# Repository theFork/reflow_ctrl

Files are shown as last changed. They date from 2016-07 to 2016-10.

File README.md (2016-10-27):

# Reflow Controller
A simple-as-possible reflow oven controller. It uses the [uMIDI](https://github.com/theFork/uMIDI) board and library as microcontroller and for USB host communication.

* 3.3V and 5V sourced from the controller board (uMIDI)
* Solid state relais Finder 77.11..9.8251 (15A) to power an oven from a low current 5V signal
* AD converter (MAX6675), connected to type-K thermocoupler
* Graphical host software written in Java

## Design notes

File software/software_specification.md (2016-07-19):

# System Overview
The system consists of a
* host system (linux-capable computer), a
* uMIDI board, the
* reflow controller board, a
* type K thermocouple as well as a
* a pizza oven.

------------------------------------------------------------------------------

# MCU firmware

## Reflow Board Interface
The reflow board IS connected to uMIDI header GPIO1 as follows:

| Pin | Function |
|-----|---|
| 2 | PWR |
| 5 | SCK |
| 7 | ~CS |
| 9 | MISO |

The reflow board IS equipped with a MAX6675 cold junction compensator and
AD-conversion chip.

## Host Interface
The uMIDI board is attached to the host system via USB and acts as a TTY device.

### Oven Shot
Activates the oven for a given duration in milliseconds:
``` 
shot <T>
```

The uMIDI board activates the oven for the given duration.
After activation it acknoledges by echoeing the shot command
with the given duration.

### Measure Temperature
Using the temp command

```
temp
```

the host requests the current temperature. The uMIDI replies in celius.

------------------------------------------------------------------------------

# Host Software
* Implemented in Python (3 or greater)
* Command line interface
* Create a temperature plot
* Implement temperature control to apply a given temperature profile

## Temperature profile
A profile consists of the following parameters, wheras upper case T stands for
a temperature whereas a lower case t represents a duration.
* T_preheat
* t_preheat
* T_reflow
* t_reflow
* T_max

The controller should not exceed T_max for more than 5s.

The profile MAY also define a maximum ramp down rate.

## Temperature plot
* A time curve of the temperature
* MUST be updated automaticaly
* SHOULD include a live view of the current temperature

SHOULKD be implemented using a python plot library (pyplot or mathplotlib), MAY also be
implemented using Gnuplot.

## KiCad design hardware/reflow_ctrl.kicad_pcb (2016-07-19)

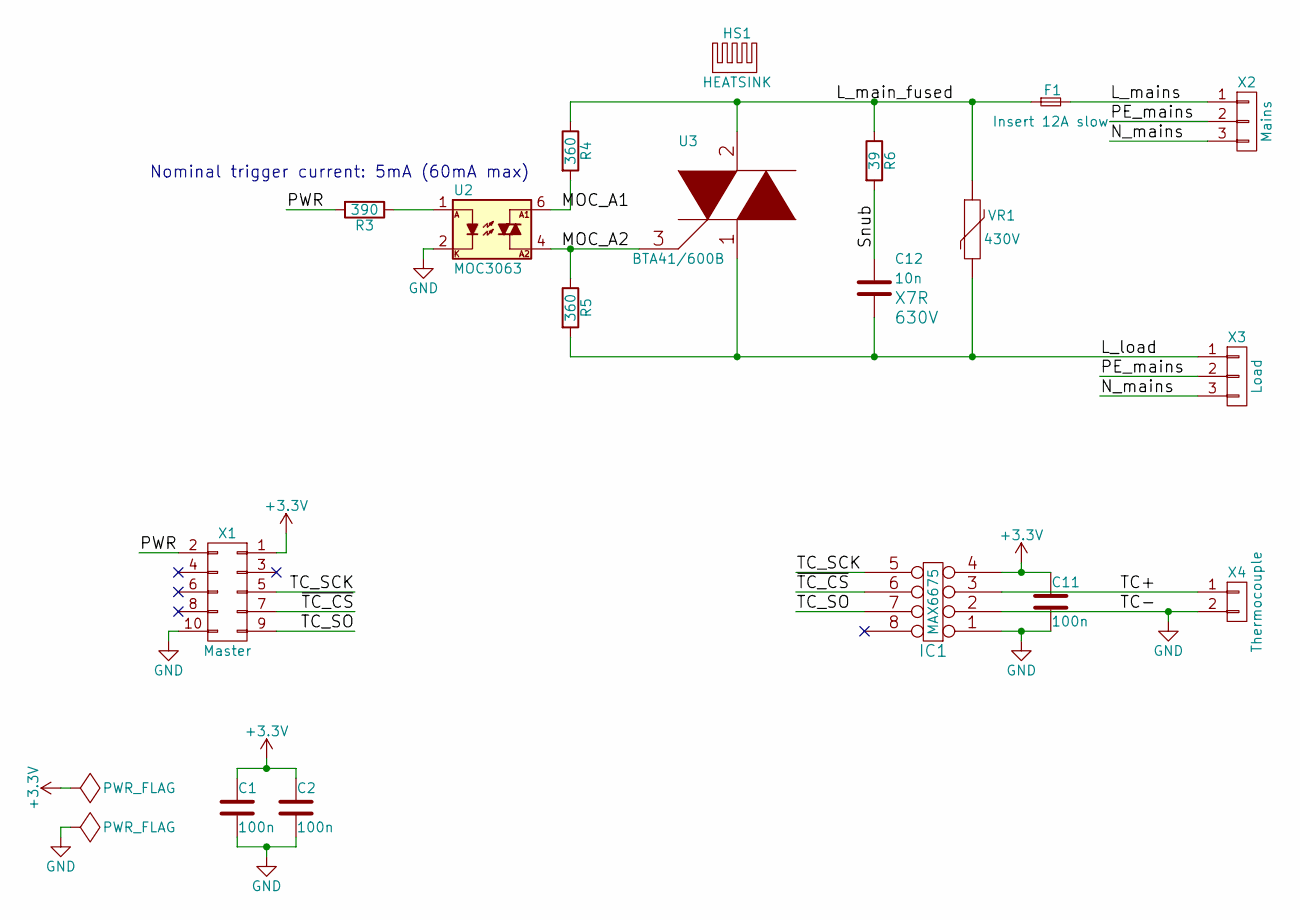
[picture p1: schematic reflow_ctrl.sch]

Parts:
C1, C2, C11: 100n; Pas_0603
C12: 10n; Pas_1206; Voltage 630V
F1: Insert 12A slow; Fuseholder_Schurter_20x5; Manufacturer Part Number 0031.8231
HS1: HEATSINK; Mech-Heatsink_Fischer_SK129_STS; Manufacturer Part Number SK 129-50 STS
IC1: MAX6675; SOIC-8_3.9x4.9mm_Pitch1.27mm
R3: 390; Pas_0603
R4, R5: 360; Pas_1206
R6: 39; Pas_1206
U2: MOC3063; Semi-Optotriac_MOC3063-SMD; Manufacturer Part Number MOC3063SR2VM
U3: BTA41/600B; TO-247_Vertical_Neutral123_largePads; Manufacturer Part Number BTA41-600BRG
VR1: 430V; RV_Disc_D7_W4.5_P5; Manufacturer Part Number S14K275
X1: Master; Con-boxed_header-THT
X2: Mains; Mains_Solder
X3: Load; Mains_Solder
X4: Thermocouple; Pinhead1-2

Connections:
+3V3: C1.1, C2.1, C11.1, IC1.4, X1.1
/L_load: C12.2, R5.2, U3.1, VR1.2, X3.1
/L_main_fused: F1.1, R4.1, R6.1, U3.2, VR1.1
/L_mains: F1.2, X2.1
/MOC_A1: R4.2, U2.6
/MOC_A2: R5.1, U2.4, U3.3
/N_mains: X2.3, X3.3
/PE_mains: X2.2, X3.2
/PWR: R3.2, X1.2
/Snub: C12.1, R6.2
/TC+: IC1.3, X4.1
/TC_SCK: IC1.5, X1.5
/TC_SO: IC1.7, X1.9
/~TC_CS: IC1.6, X1.7
GND: C1.2, C2.2, C11.2, IC1.1, IC1.2, U2.2, X1.10, X4.2
unnamed: R3.1, U2.1

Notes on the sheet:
Nominal trigger current: 5mA (60mA max)

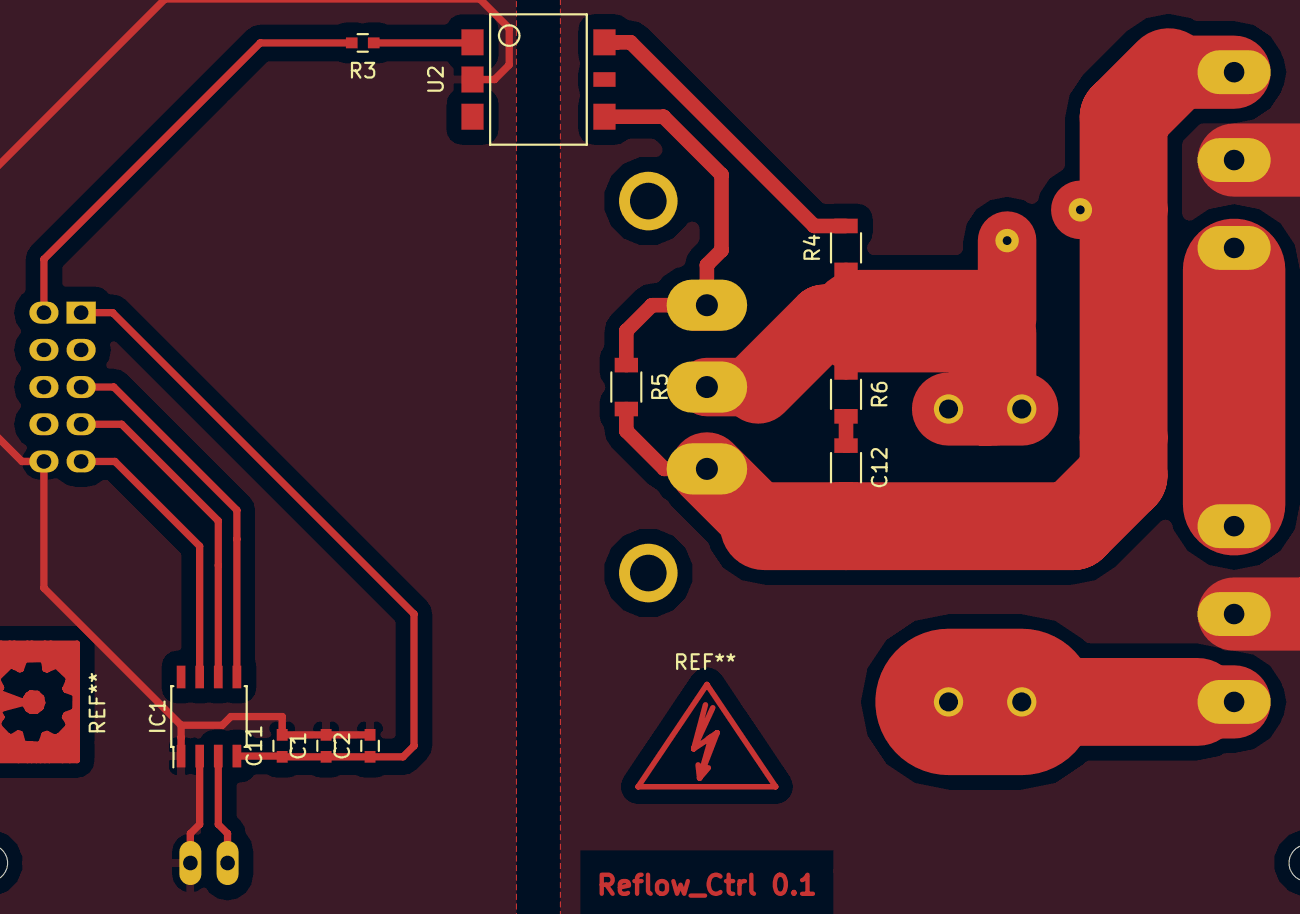
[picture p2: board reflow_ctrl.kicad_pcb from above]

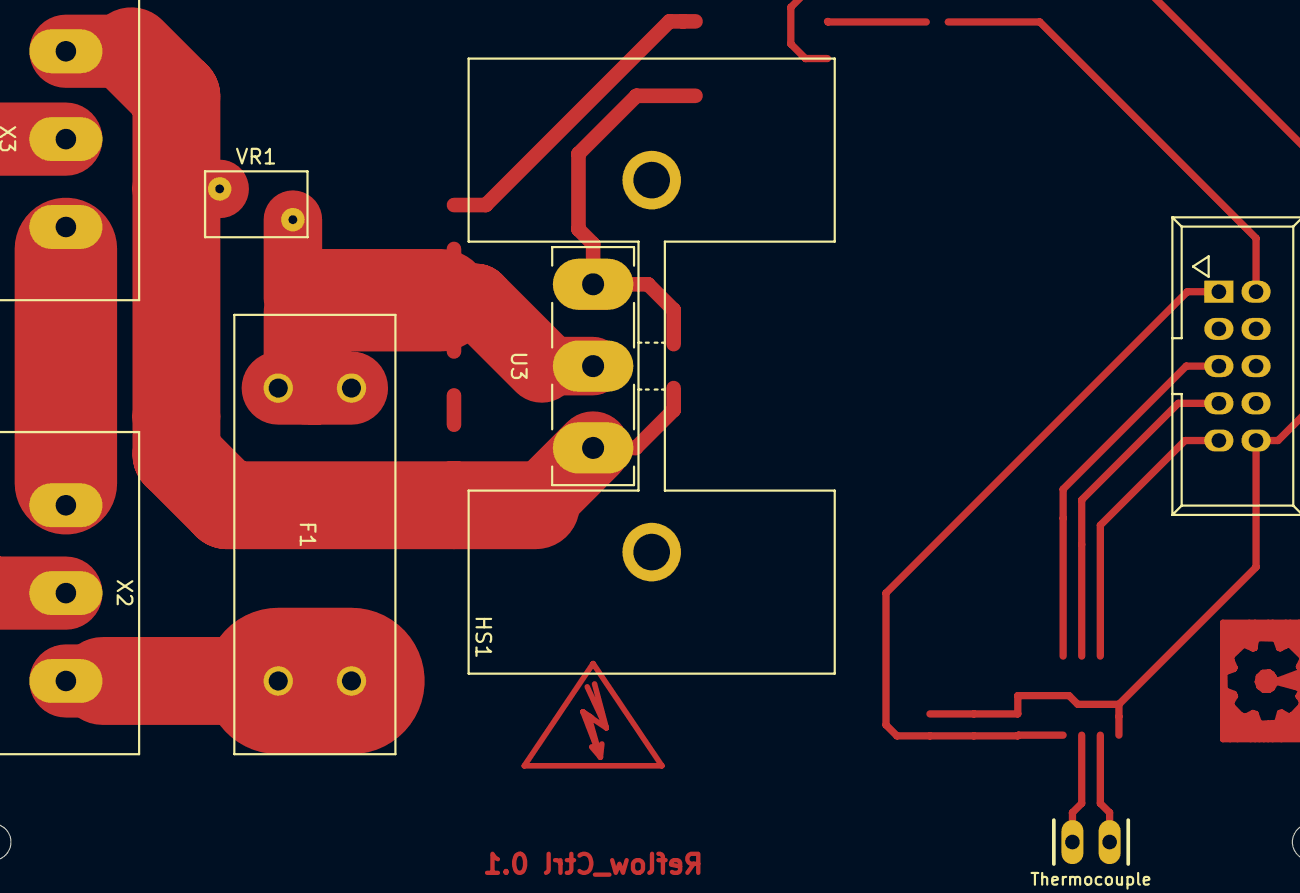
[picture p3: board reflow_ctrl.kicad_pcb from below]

Board: 2 copper layers, 18 parts (8 on the bottom side), 16 nets.

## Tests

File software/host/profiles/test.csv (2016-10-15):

# Temperature profile for testing
# Syntax: <Duration> | <Temperature>
# <Duration> | <TemperatureStart>..<TemperatureEnd>
180 | 50..100
180 | 80
180 | 80..150
180 | 130

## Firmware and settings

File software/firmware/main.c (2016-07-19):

/// \file
/// \brief      Entry point and main loop of the uMIDI firmware

/*
 * Copyright 2012-2015 Sebastian Neuser
 *
 * This file is part of the uMIDI firmware.
 *
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
 * You should have received a copy of the GNU General Public License
 * along with the uMIDI firmware.  If not, see <http://www.gnu.org/licenses/>.
 */

#include <avr/interrupt.h>
#include <avr/wdt.h>

#include "lib/background_tasks.h"
#include "lib/gpio.h"
#include "lib/leds.h"
#include "lib/serial_communication.h"
#include "lib/spi.h"
#include "lib/system.h"
#include "lib/usb.h"

#include "config.h"
#include "app.h"


////////////////////////////////////////////////////////////////
//                     V A R I A B L E S                      //
////////////////////////////////////////////////////////////////



////////////////////////////////////////////////////////////////
//      F U N C T I O N S   A N D   P R O C E D U R E S       //
////////////////////////////////////////////////////////////////

/// \brief      Initialization and endless loop with background tasks
int main( void )
{
    // Configure clock and timers
    configure_system_clock();
    enable_usb_pll();

    // Initialize modules
    init_leds_module();
    init_gpio_module(gpio_mappings, gpio_mappings_size);
    init_spi_module(&spi_config);
    init_background_tasks(high_frequency_tasks, high_frequency_tasks_size,
                          mid_frequency_tasks,  mid_frequency_tasks_size,
                          low_frequency_tasks,  low_frequency_tasks_size);
    init_usb_module();
    init_serial_communication(serial_commands, serial_commands_size);

    restore_temp_offset();

    // set watchdog for 128ms
    wdt_enable(WDT_PER_128CLK_gc);

    // enable interrupts
    PMIC.CTRL = PMIC_LOLVLEN_bm;
    sei();

    // Blink green LED
    blink_led(LED_GREEN, F_TASK_SLOW);

    // Main loop
    while (true) {
        process_background_tasks();
        wdt_reset();
    }

    return 0;
}

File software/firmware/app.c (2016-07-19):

/// \file
/// \brief      Implementation of an application specific module
/// \see        app.h

/*
 * Copyright 2015 Sebastian Neuser
 *
 * This file is part of the uMIDI firmware.
 *
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
 * You should have received a copy of the GNU General Public License
 * along with the uMIDI firmware.  If not, see <http://www.gnu.org/licenses/>.
 */

#include <stdlib.h>
#include <string.h>

#include "lib/leds.h"
#include "lib/usb.h"

#include "config.h"
#include "app.h"


////////////////////////////////////////////////////////////////
//                     V A R I A B L E S                      //
////////////////////////////////////////////////////////////////

static uint16_t heater_timeout = 0;

static int16_t temp_offset = 0;
static uint16_t temp_offset_eemem EEMEM;


////////////////////////////////////////////////////////////////
//      F U N C T I O N S   A N D   P R O C E D U R E S       //
////////////////////////////////////////////////////////////////

/// \brief      Handler for the `led` command
bool exec_led(const char* command)
{
    // Abort if the command is malformed
    if (strlen(command) != 7 || command[3] != ' ' || command[5] != ' ') {
        usb_puts("Malformed command" USB_NEWLINE);
        return false;
    }

    // Parse LED(s) to manipulate
    struct led* led;
    switch (command[4]) {
    case 'g':
        led = led_green;
        break;

    case 'r':
        led = led_red;
        break;

    default:
        usb_puts("No such LED" USB_NEWLINE);
        return false;
    }

    // Parse and execute action
    switch (command[6]) {
    case 'b':
        blink_led(led, F_TASK_SLOW);
        break;

    case 'f':
        flash_led(led);
        break;

    case 't':
        toggle_led(led);
        break;

    default:
        usb_puts("No such action" USB_NEWLINE);
        return false;
    }

    return true;
}

bool exec_shot(const char * const command)
{
    if (strlen(command) < 6 || command[4] != ' ') {
        usb_puts("Malformed command" USB_NEWLINE);
        return false;
    }

    uint16_t length = strtol(command+5, NULL, 10);
    usb_printf("Enabling heater for %u ms" USB_NEWLINE, length*10);

    // update (i.e. overwrite) countdown
    heater_timeout = length;

    return true;
}

bool exec_offs(const char* command)
{
    if (strlen(command) < 6 || command[4] != ' ') {
        usb_puts("Malformed command" USB_NEWLINE);
        return false;
    }

    temp_offset = strtol(command+5, NULL, 10);
    eeprom_write_word(&temp_offset_eemem, temp_offset);
    return true;
}

bool exec_temp(const char * const command)
{
    if (strlen(command) != 4) {
        usb_puts("Malformed command" USB_NEWLINE);
        return false;
    }

    // "Send" dummy value to recieve data
    spi_select(true);
    uint16_t input_word = spi_transceive(0);
    spi_select(false);

    // Abort if no thermo couple is connected
    if (input_word & 0x4) {
        usb_puts("Error: No thermo couple connected!" USB_NEWLINE ":-(");
        return true;
    }

    // Parse and print temperature
    uint16_t temperature = input_word >> 3;
    temperature += temp_offset;

    const char* fractional = "00";
    switch (temperature % 4) {
        case 3:
            fractional = "75";
            break;
        case 2:
            fractional = "50";
            break;
        case 1:
            fractional = "25";
            break;
        default:
            break;
    }
    temperature >>= 2;

    usb_printf("Temperature: %4u.%s" USB_NEWLINE, temperature, fractional);
    return true;
}

void heat_control_task(void)
{
    // Heater is on in case there is still timeout left
    if (heater_timeout > 0) {
        heater_timeout--;
        gpio_drive_high(gpio.header1.pin2);
        set_led(led_red, true);
    }
    // Turn off the heater afterwards
    else {
        gpio_drive_low(gpio.header1.pin2);
        set_led(led_red, false);
    }
}

void restore_temp_offset(void)
{
    temp_offset = eeprom_read_word(&temp_offset_eemem);
}

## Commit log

2016-01-31 Initial schematic
    [reflow_ctrl.kicad_pcb, reflow_ctrl.sch]
2016-01-31 Add uMIDI.pretty footprints module
2016-01-31 Assign some footprints
    [reflow_ctrl.sch]
2016-01-31 Move protection earth between L and N
    [reflow_ctrl.sch]
2016-01-31 Add and assign mains terminal footprint
    [reflow_ctrl.sch]
2016-01-31 Add supplier links and optotriac footprint
    [reflow_ctrl.sch]
2016-02-01 Sanetize output circuit; Add varistor
    [reflow_ctrl.sch]
2016-02-01 Add fuse holder footprint
    [reflow_ctrl.sch]
2016-02-01 Assign all footprints
    [reflow_ctrl.sch]
2016-02-01 Initial placement; Select pcb outline; Add TODO
    [reflow_ctrl.kicad_pcb, reflow_ctrl.sch]
2016-02-03 Use big USB-B THT connector
    [reflow_ctrl.kicad_pcb, reflow_ctrl.sch]
2016-02-15 Remove MCU circuit (use external uMIDI)
    [reflow_ctrl.sch]
2016-02-15 ERC clean
    [reflow_ctrl.sch]
2016-02-15 Update uMIDI.pretty: Fix footprint syntax (?)
2016-02-15 Update board
    [reflow_ctrl.kicad_pcb, reflow_ctrl.sch]
2016-02-15 Prepare net classes
    [reflow_ctrl.kicad_pcb, reflow_ctrl.sch]
2016-02-19 Shrink schematic page size
    [reflow_ctrl.sch]
2016-02-19 Add mounting holes
    [reflow_ctrl.kicad_pcb]
2016-02-19 Disentangle connector pinout; Start placement
    [reflow_ctrl.kicad_pcb, reflow_ctrl.sch]
2016-02-19 Add and use uMIDI.pretty generic smd packages
    [reflow_ctrl.kicad_pcb, reflow_ctrl.sch]
2016-02-19 Place and lock heatsink and triac
    [reflow_ctrl.kicad_pcb, reflow_ctrl.sch]
2016-02-19 Start place and route
    [reflow_ctrl.kicad_pcb]
2016-02-20 Revise placement; Route
    [reflow_ctrl.kicad_pcb]
2016-02-20 Finish routing
    [reflow_ctrl.kicad_pcb]
2016-02-20 Edit optotriac package; DRC clean
    [reflow_ctrl.kicad_pcb, reflow_ctrl.sch]
2016-02-20 Connect heatsink to PE
    [reflow_ctrl.kicad_pcb]
2016-02-21 Use a smaller VDR package
    [reflow_ctrl.kicad_pcb, reflow_ctrl.sch]
2016-02-21 Optimize header pinout and trace widths
    [reflow_ctrl.kicad_pcb, reflow_ctrl.sch]
2016-02-21 Add some fancy symbols
    [reflow_ctrl.kicad_pcb]
2016-06-25 Fix missing GND on TC-
    [reflow_ctrl.kicad_pcb, reflow_ctrl.sch]
2016-06-25 Implement heating function and shot command
2016-06-25 Update uMidi submodule and include SPI module in build
2016-06-25 Configure SPI module
2016-06-25 Implement temperature readout
2016-06-25 Implement temperature offset calibration via CLI
2016-07-20 Implement generic PID controller and control loop task dummy
2016-07-24 Implement and integrate profile reader
    [test.csv]
2016-07-24 DataLogger: Add optional PID controller debug traces
2016-09-24 Show temperature profile from the beginning
    [test.csv]
2016-10-04 Modify profile for first tests
    [test.csv]
2016-10-07 Add button bar; Stub action listeners
2016-10-08 Manage temperature measurement and plotting
2016-10-08 Read the temperature 5 times and return average
2016-10-08 Plot duty cycle
    [test.csv]
2016-10-15 Warn if there are major temperature differences
2016-10-15 Add and use initial pb-free profile
    [pb-free.csv]
2016-10-15 Make profile more realistic for the oven
    [pb-free.csv]
2016-10-15 Slow down heating phases
    [pb-free.csv]
2016-10-15 Create and use profile including new statement
    [test.csv]
2016-10-15 Refactor TemperatureProfileReader
2016-10-15 More refactoring; Rename to TemperatureProfile
2016-10-22 Adapt pb-free profile
    [pb-free.csv]
2016-10-22 Make reflow profile realistic for the oven
    [pb-free.csv]
2016-10-22 Increase temperature peak duration
    [pb-free.csv]
2016-10-24 Configure flowctrl and baudrate
2016-10-25 Yet again - Edit profile
    [pb-free.csv]

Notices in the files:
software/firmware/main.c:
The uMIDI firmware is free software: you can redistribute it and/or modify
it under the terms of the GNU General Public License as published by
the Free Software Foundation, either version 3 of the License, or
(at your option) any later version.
